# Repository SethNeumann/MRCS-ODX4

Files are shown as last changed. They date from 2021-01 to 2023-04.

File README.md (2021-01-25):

# REPO NAME: MRCS-ODX4
## License: Creative Commons Attribution-NonCommercial-ShareAlike

The ODX-4 has been updated to version 2.0. Based on customer feedback, and our design and installation experience, the changes were made to provide more efficient and flexible physical layout of some components.  Rev 2.0 boards are 100% backward compatible with older versions. No software changes are needed.

- Board size 2.7" x 3.9" 69 x 100 mm

- The board can be split into two DCC sections by cutting the SPLIT pad jumper trace.

- DCC Bus connections are 5 mm screw terminal blocks.

- A power, Ground, and Detector connection is provided on a 6-position .100 (2.54 mm) screw terminal block.

The ODX4 provides an economical and convenient mounting for up to four cpOD-M detectors or DCC_OD "Optimized Detectors."  0.156 screw terminals are provided for 12V power, ground, DCC, and four logic outputs, one for each detector position.  DCC_OD are available as boards from JLC Enterprises.

The ODX4 mounts in our DIN-Rail snap track.

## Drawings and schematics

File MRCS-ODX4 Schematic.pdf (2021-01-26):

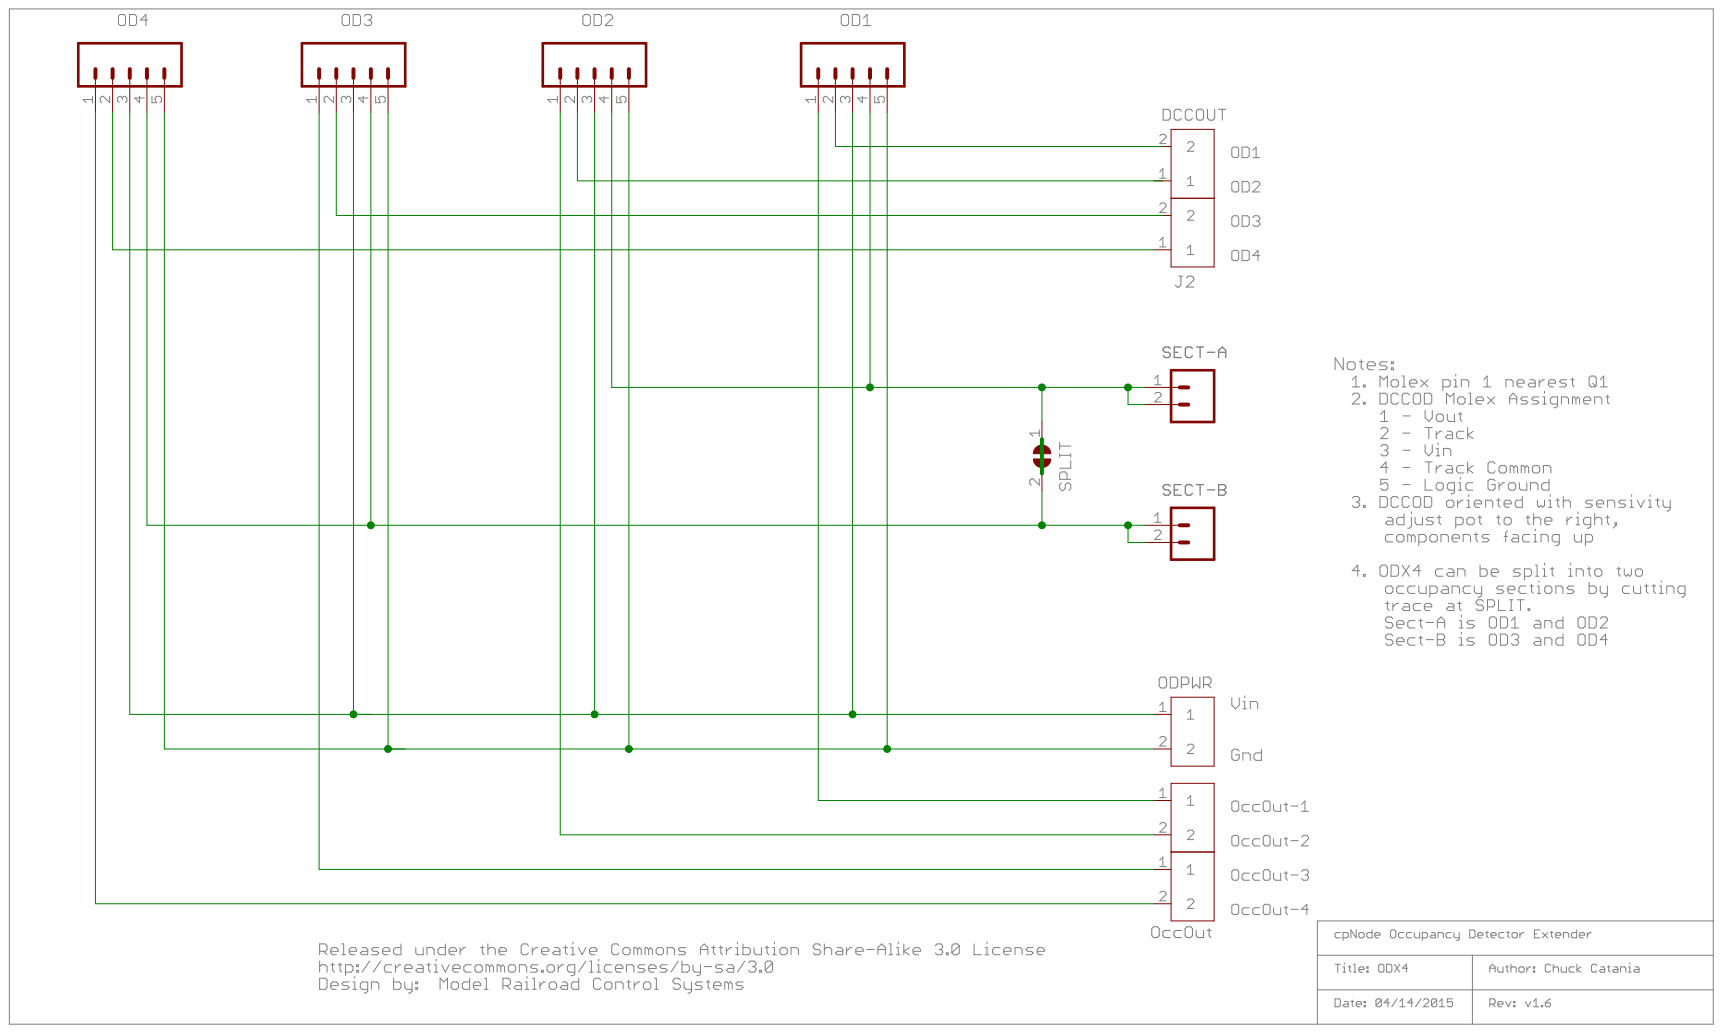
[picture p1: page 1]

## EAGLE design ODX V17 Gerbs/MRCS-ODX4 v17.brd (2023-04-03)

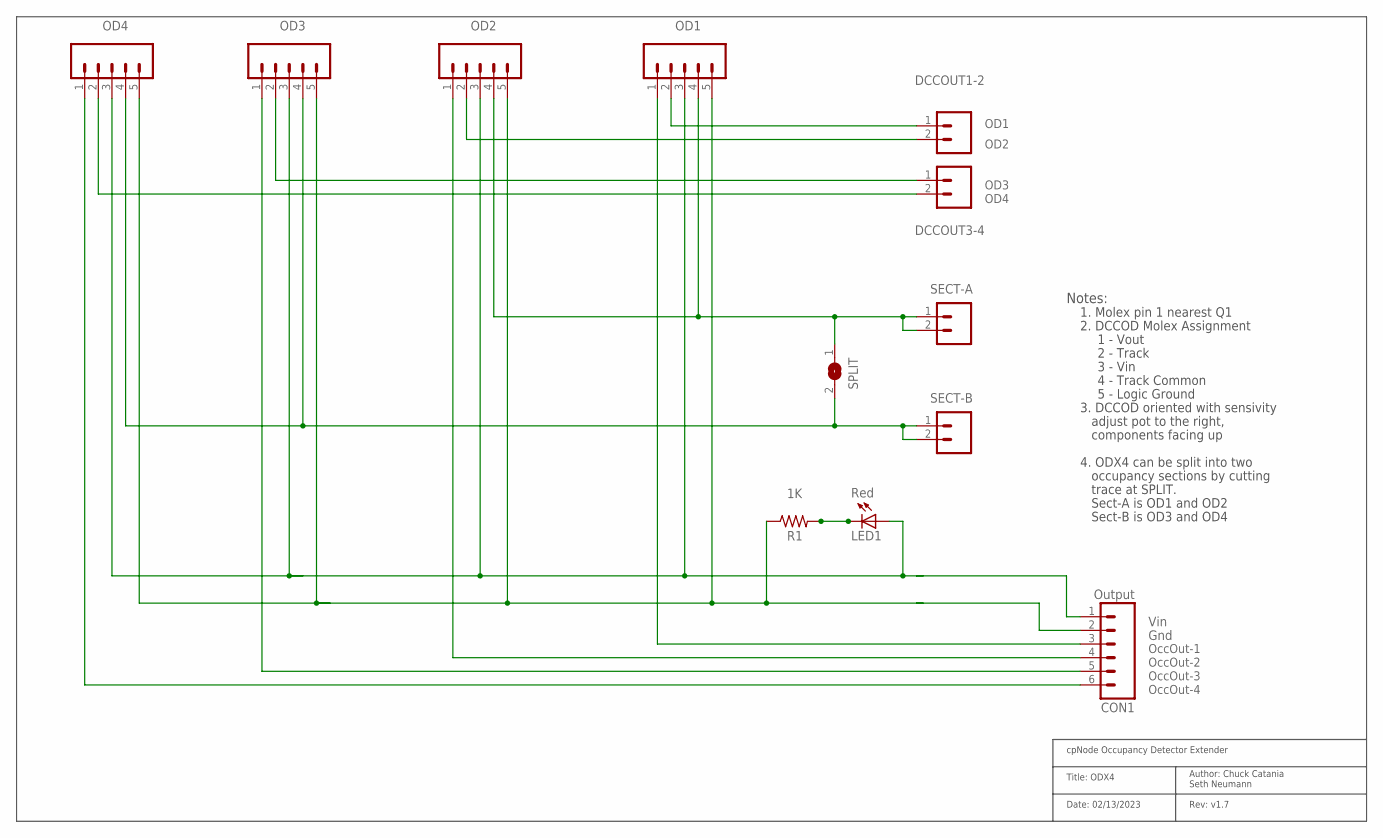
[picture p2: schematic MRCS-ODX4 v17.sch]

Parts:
CON1: Output; MOLEX-1X6_LOCK
DCCOUT1-2, DCCOUT3-4: CONNECTOR-M025MM-LOCK; SCREWTERMINAL-5MM-2
LED1: Red; LED3MM
OD1, OD2, OD3, OD4: M05PTH_LONGPADS; 1X05_LONGPADS
R1: 1K; AXIAL-0.4-RES
SECT-A: M025MM; SCREWTERMINAL-5MM-2
SECT-B: M025MM; SCREWTERMINAL-5MM-2
SPLIT: SJW

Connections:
GND: CON1.2, OD1.5, OD2.5, OD3.5, OD4.5, R1.P$1 (1)
unnamed: DCCOUT3-4.2 (B), OD4.2
unnamed: CON1.3, OD1.1
unnamed: DCCOUT1-2.1 (A), OD1.2
unnamed: DCCOUT1-2.2 (B), OD2.2
unnamed: LED1.K (C), R1.P$2 (2)
unnamed: CON1.6, OD4.1
unnamed: OD3.4, OD4.4, SECT-B.1, SECT-B.2, SPLIT.2
unnamed: OD1.4, OD2.4, SECT-A.1, SECT-A.2, SPLIT.1
unnamed: CON1.4, OD2.1
unnamed: DCCOUT3-4.1 (A), OD3.2
unnamed: CON1.5, OD3.1
VIN: CON1.1, LED1.A, OD1.3, OD2.3, OD3.3, OD4.3

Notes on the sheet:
Rev: v1.7
Date: 02/13/2023
Title: ODX4
cpNode Occupancy Detector Extender
Author: Chuck Catania Seth Neumann
Vin
Gnd
OccOut-1
OccOut-2
OccOut-3
5 - Logic Ground
4 - Track Common
3 - Vin
2 - Track
1 - Vout
2. DCCOD Molex Assignment
Notes:
3. DCCOD oriented with sensivity
adjust pot to the right,
components facing up
OD1
OD2
OD3
OD4
OccOut-4
1. Molex pin 1 nearest Q1
4. ODX4 can be split into two
occupancy sections by cutting
trace at SPLIT.
Sect-A is OD1 and OD2
Sect-B is OD3 and OD4

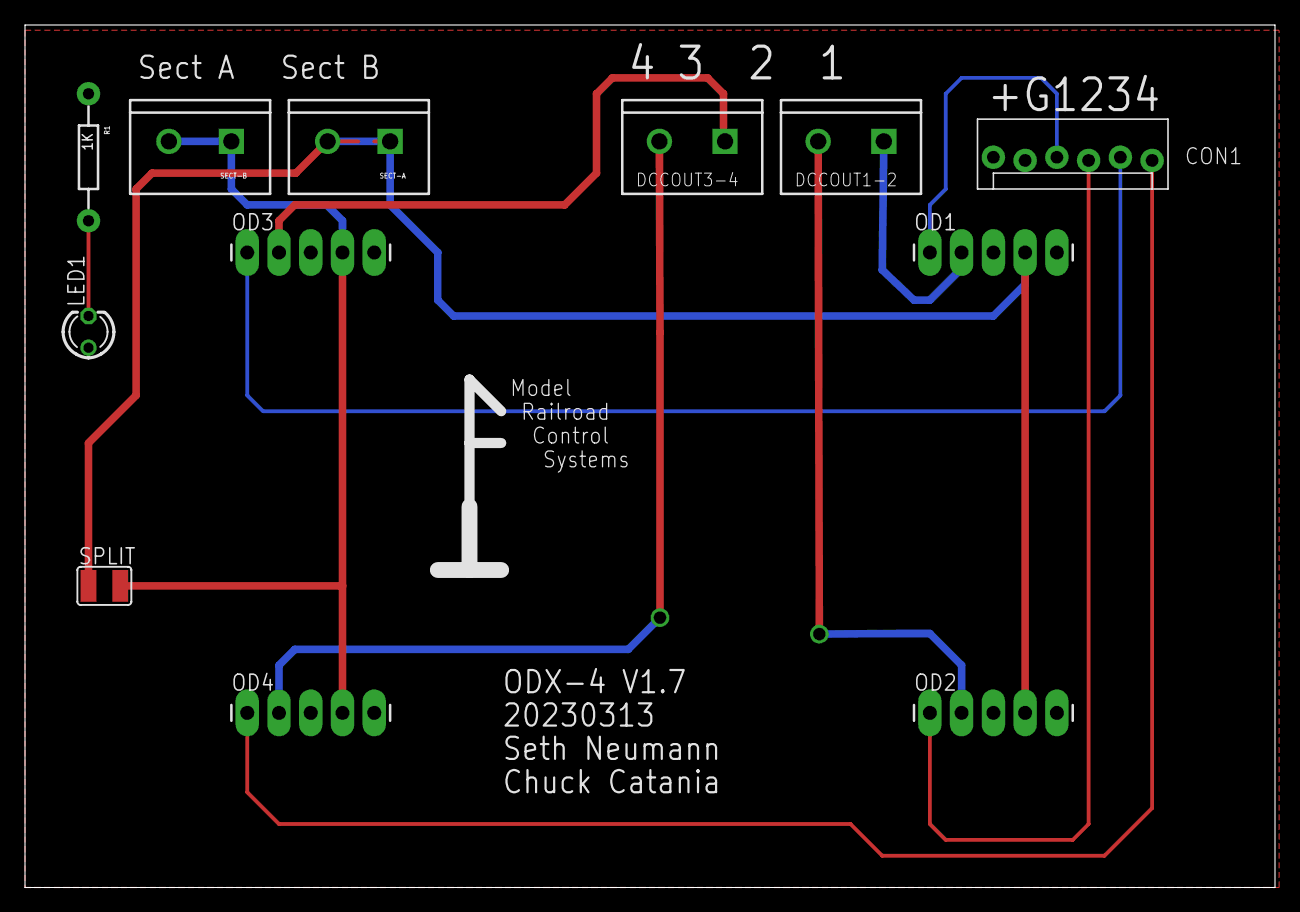
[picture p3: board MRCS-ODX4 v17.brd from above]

Board: 2 copper layers, 100.0 x 69.0 mm, 13 parts (0 on the bottom side), 13 nets.

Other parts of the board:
U$1: MRCS-LOGO

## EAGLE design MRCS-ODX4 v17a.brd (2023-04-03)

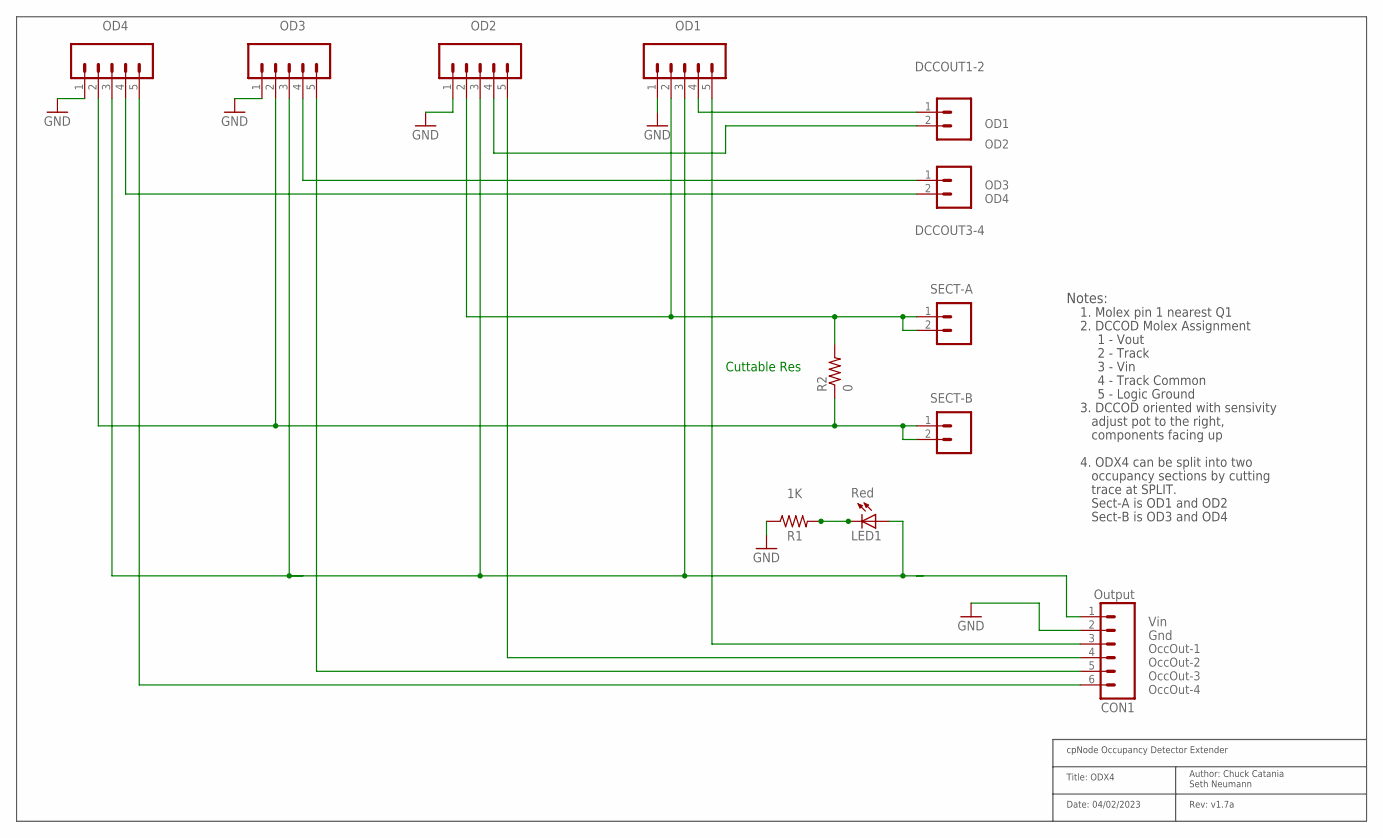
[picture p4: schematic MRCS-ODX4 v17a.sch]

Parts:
CON1: Output; MOLEX-1X6_LOCK
DCCOUT1-2, DCCOUT3-4: CONNECTOR-M025MM-LOCK; SCREWTERMINAL-5MM-2
LED1: Red; LED3MM
OD1, OD2, OD3, OD4: CONNECTOR-M051.56; KK-156-5
R1: 1K; AXIAL-0.4-RES
R2: 0; CUT-R
SECT-A: M025MM; SCREWTERMINAL-5MM-2
SECT-B: M025MM; SCREWTERMINAL-5MM-2

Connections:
GND: CON1.2, OD1.1, OD2.1, OD3.1, OD4.1, R1.P$1 (1)
unnamed: CON1.6, OD4.5
unnamed: LED1.K (C), R1.P$2 (2)
OCCOUT1: CON1.3, OD1.5
OCCOUT2: CON1.4, OD2.5
OCCOUT3: CON1.5, OD3.5
SECT-A: OD1.2, OD2.2, R2.P1 (2), SECT-A.1, SECT-A.2
SECT-B: OD3.2, OD4.2, R2.P2 (1), SECT-B.1, SECT-B.2
TO1: DCCOUT1-2.1 (A), OD1.4
TO2: DCCOUT1-2.2 (B), OD2.4
TO3: DCCOUT3-4.1 (A), OD3.4
TO4: DCCOUT3-4.2 (B), OD4.4
VIN: CON1.1, LED1.A, OD1.3, OD2.3, OD3.3, OD4.3

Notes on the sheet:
Rev: v1.7a
Date: 04/02/2023
Title: ODX4
cpNode Occupancy Detector Extender
Author: Chuck Catania Seth Neumann
Vin
Gnd
OccOut-1
OccOut-2
OccOut-3
5 - Logic Ground
4 - Track Common
3 - Vin
2 - Track
1 - Vout
2. DCCOD Molex Assignment
Notes:
3. DCCOD oriented with sensivity
adjust pot to the right,
components facing up
OD1
OD2
OD3
OD4
OccOut-4
1. Molex pin 1 nearest Q1
4. ODX4 can be split into two
occupancy sections by cutting
trace at SPLIT.
Sect-A is OD1 and OD2
Sect-B is OD3 and OD4
Cuttable Res

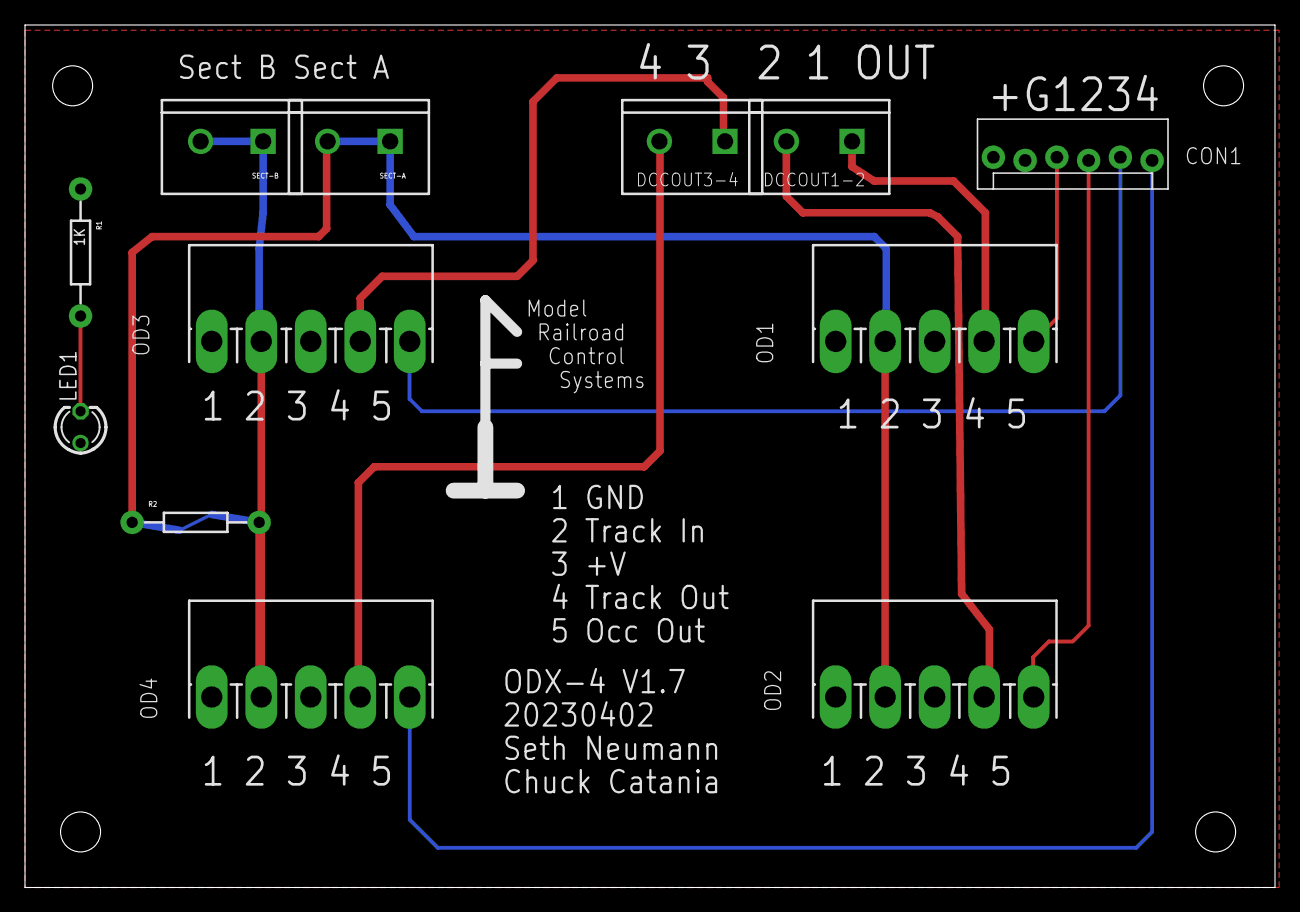
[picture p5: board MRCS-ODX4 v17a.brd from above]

Board: 2 copper layers, 100.0 x 69.0 mm, 15 parts (0 on the bottom side), 13 nets.

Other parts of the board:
U$1: MRCS-LOGO
U$2: MRCSLOGOBTM
U$3: CA-PROP65WARNING

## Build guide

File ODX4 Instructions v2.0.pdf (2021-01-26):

# ODX4 Assembly Instructions

Revision v2.0 02/01/2016

Introduction
This document describes the functional blocks of the ODX4 block detector motherboard and how to assemble it.

Revision History
v1.0 | 01/29/2014 | CC
v1.1 | 06/08/2014 | CC
v2.0 | 02/01/2016 | CC

Model Railroad Control Systems www.modelrailroadcontrolsystems.com

Chuck Catania, chuck@modelrailroadcontrolsystems.com Seth Neumann, seth@modelrailroadcontrolsystems.com

## Table of Contents

1. ODX4 SYSTEM OVERVIEW | 3
2. BILL OF MATERIALS | 7
3. ASSEMBLY | 7

## Table of Figures

FIGURE 1 ODX4 COMPONENT LOCATIONS | 3
FIGURE 2 CPOD/DCCOD MOUNTING ORIENTATION | 4
FIGURE 3 TRACK BLOCK CONNECTION EXAMPLE | 5
FIGURE 4 TWO BREAKER SECTIONS (SPLIT) TRACK BLOCKS | 6

### 1. ODX4 SYSTEM OVERVIEW

The Occupancy Detector Extender 4 (ODX4) provides mounting and interconnects for up to four MRCS cpOD or JLC DCCOD DCC block occupancy detectors.

Vin power can be 5v/12v for the cpOD or 12v for the DCCOD connected to the marked screw terminals, Vin, GND.

The DCC bus input is connected to the DCC IN terminal block. The DCC IN terminal block has four positions, which are bridged together. The ODX4 DCC In can be split by cutting the SPLIT trace. Only one side of the DCC bus (e.g. RAIL A) is connected to the ODX4. The track block feeders are connected to the DCC Out terminals.

Detector outputs for control logic are connected to DccOut1 to DccOut4.

The MRCS cpOD or C/MRI DCCOD are plugged into the .156" Molex headers, component side up, with the sensitivity potentiometer to the right. Figure 2 shows the orientation.

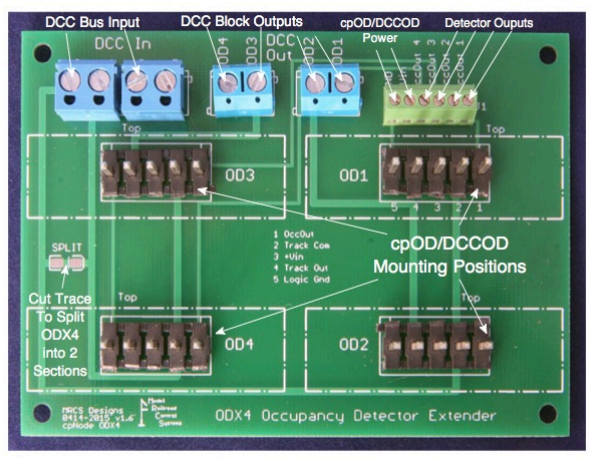
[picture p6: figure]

Figure 1 ODX4 Component Locations

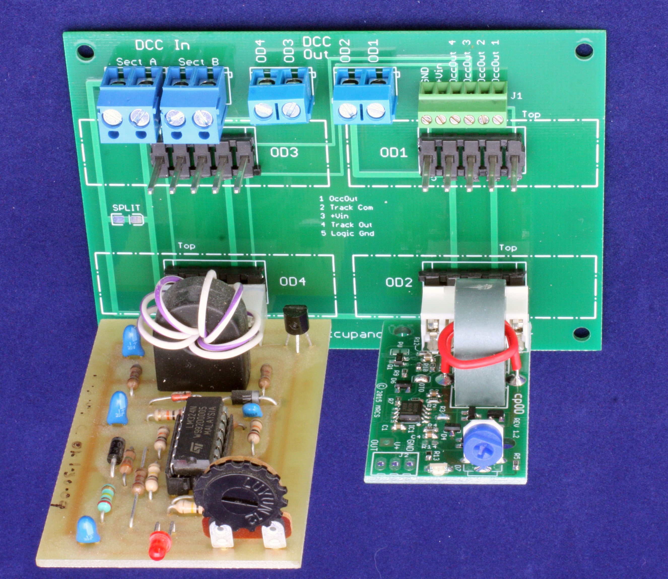
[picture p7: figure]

Figure 2 cpOD/DCCOD Mounting Orientation

To configure the ODX4 for one to four detector sections, one side of the DCC input is connected to the DCC In terminal and passes out through the same terminal block to the next ODX4. All detectors plugged into the ODX4 will feed the corresponding output track feeders from the same DCC power district.

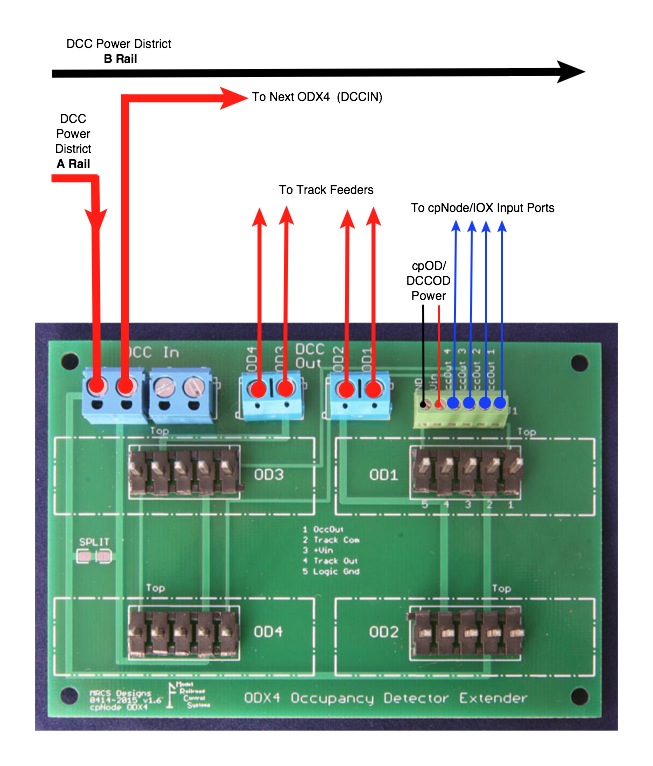
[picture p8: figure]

Figure 3 Track Block Connection Example

To configure the ODX4 for two separate breaker districts, cut the trace marked "SPLIT". This will divide the ODX4 into two separate sections, one servicing OD1 and OD2, the other OD3 and OD4.

The diagram shows breaker #1 connected to the left hand DCC In terminal block. OD3 and OD4 feeders are connected to the corresponding OD3,OD4 DCC Out terminal block.
Breaker #2 is connected to the right hand DCC In and OD1 and OD2 are connected to the OD1,OD2 DCC Out terminal block.

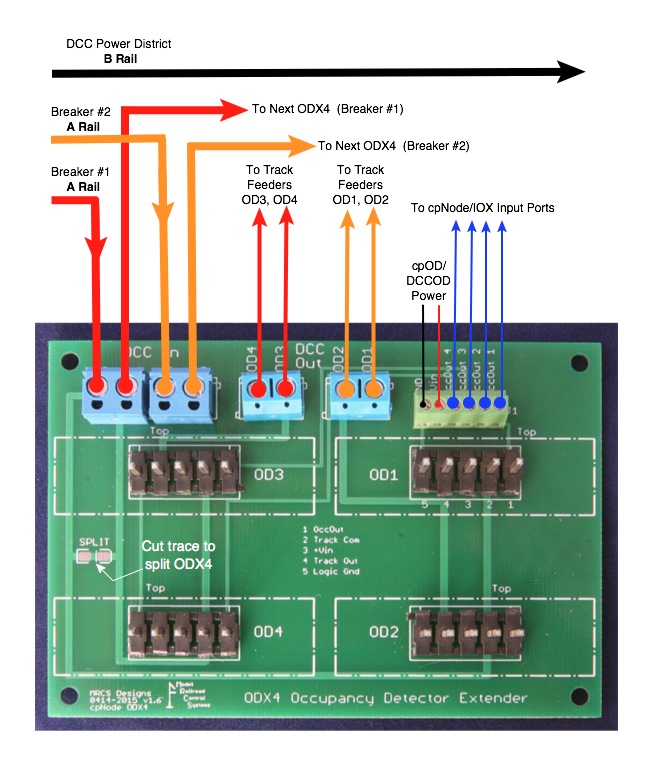
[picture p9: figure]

Figure 4 Two Breaker Sections (Split) Track Blocks

### 2. BILL OF MATERIALS

Description | Ref | Qty | Supplier | Part No.
cNode ODX4 PCB v2.0 | PCB1 | 1 | MRCS | ODX4
Male pin HDR 5 Pin .156" | OD1,OD2,OD3,OD4 | 4 | Digikey | WM4623-ND
6 pos Screw Terminal 2.54 mm | J1 | 1 | Electronic Salon
2 pos Screw Terminal 5 mm | J2,J3 | 2 | Jameco | 2094485
2 pos Screw Terminal 5 mm | SECTA,SECTB | 2 | Jameco | 2094485

### 3. ASSEMBLY

[ ] All of the components are through-hole technology.

[ ] Install the 5mm, two position, screw terminals (DCCIN, DCCOUT)

[ ] Install the 2.54 mm, 6 position, screw terminals (OD Power, Detector outputs 1-4)

[ ] Install the .156", 5 position Molex male headers, (OD1, OD2, OD3, OD4)

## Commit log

2021-01-26 migrated existing ODX v16 files
    migrated existing ODX v16 files
    [EagleTemplate-new.brd, EagleTemplate-new.sch, MRCS-ODX4.brd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]
2021-01-26 Create MRCS-ODX4 Schematic.pdf
    added pdf schematic for users who don't use EAGLE
2023-04-03 V1.7
    moved 5mm connectors, added power LED
2023-04-03 V1.7
    moved 5mm connectors, updated labels, added power LEDs
    [MRCS-ODX4 v17.brd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]

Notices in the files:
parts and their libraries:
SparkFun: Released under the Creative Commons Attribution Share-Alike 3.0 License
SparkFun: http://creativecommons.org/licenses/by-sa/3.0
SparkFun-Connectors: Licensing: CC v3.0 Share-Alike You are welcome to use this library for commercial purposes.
